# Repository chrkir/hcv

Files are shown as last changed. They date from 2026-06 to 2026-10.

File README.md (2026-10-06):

# Viessmann Vitocal (E3) CAN-Bus to MQTT Bridge with Home Assistant Support

## Please also read the HCV Description in the docu folder.

An isolated, passive CAN-bus adapter to fetch local data from Viessmann E3-generation heat pumps (e.g., Vitocal 250-A, 252-A) and stream it via Wi-Fi to MQTT with native Home Assistant Auto-Discovery.

## 🚀 Key Features

- **100% Local Control:** No internet dependency, no official ViCare Cloud API rate limits.
- **Hardware Protection:** Features full galvanic isolation to protect your expensive heat pump from electrical damage.
- **Passive Sniffing:** Read-only operation ensures zero interference with the heating system's warranty.
- **Plug & Play for Home Assistant:** Built-in MQTT Discovery automatically creates all entities (temperatures, flow rates in L/h, energy in kWh, and states) without writing a single line of YAML.
- **Universal Compatibility:** Works seamlessly with Home Assistant, ioBroker, Node-RED, openHAB, and Symcon.

---

## 🔀 Supported Series & Target Selection (V200 vs. V250)

This project supports both the **E3 Generation (e.g., Vitocal 250-A, 252-A)** and the **V200/WO1C CAN Protocol (e.g., Vitocal 200-S, 200-A, HCV)** via dedicated software builds.

| Feature / Setting | Vitocal 250 (E3 Series) | Vitocal 200 (HCV / WO1C Series) |
| :--- | :--- | :--- |
| **Firmware Target** | Vitocal-250 Build | Vitocal-200 Build |
| **DID Profile File** | `vcalobj.did` | `vcalobj200.did` |
| **DID Format** | Decimal (e.g., `881`, `548`) | Hexadecimal (e.g., `0x0371`, `0x0100`) |
| **Log File** | `canLog250.txt` | `canLog200.txt` |
| **Bus Protocol** | E3 CAN Specification | WO1C CAN Variant |

---

### Selective DID Profile (`vcalobj200.did`) for Vitocal 200

When using the **Vitocal 200 Firmware**, the DID profile file must be uploaded as `vcalobj200.did`. Addresses correspond strictly to the WO1C / HCV hexadecimal address map:

```did
# ==============================================================================
# embdes Viessmann Vitocal 200 / WO1C Custom DID Profile
# Line comments starting with '#' are fully supported.
# ==============================================================================

# Core Temperatures & Controls (WO1C Hex Format)
{0x0100, OutdoorTemp, Aussentemperatur, 0, 1, FLOAT_TEMP_10},
{0x0371, OperatingMode, Betriebsart, 0, 1, INTEGER},
{0x0401, MixerPumpState, StatusMischerPumpe, 0, 1, ON_OFF},

```

## 🛠️ Project Structure & License Model

This project follows a hybrid **Open Hardware / Commercial Software** model to support the community while funding the extensive reverse-engineering work behind the Viessmann CAN protocols.

### 1. Open Hardware (Free)
All hardware files are open-source. You can find the schematics, PCB layout files (KiCAD/EasyEDA), Bill of Materials (BOM), and a 3D-printable enclosure STL file in the `/hardware` folder. Feel free to DIY and order your own boards.

### 2. Pre-Assembled Hardware (Optional)
If you do not want to solder SMD components or lack the equipment, you can buy a fully assembled and tested hardware unit inside its enclosure directly from me for **approx. €35 + MwSt ** (plus shipping from Germany). 

### 3. Firmware & Software License
- **Demo Version (Free):** Includes the local Wi-Fi/MQTT captive portal captive setup, hardware connection test, and displays your unique ESP32 Chip ID.
- **Full Version (€48 + MwSt)** Unlocks all heating data points, daily energy counters, and native Home Assistant Auto-Discovery. It is a one-time payment per device and works **100% offline** (via a license file uploaded to the file system).

---

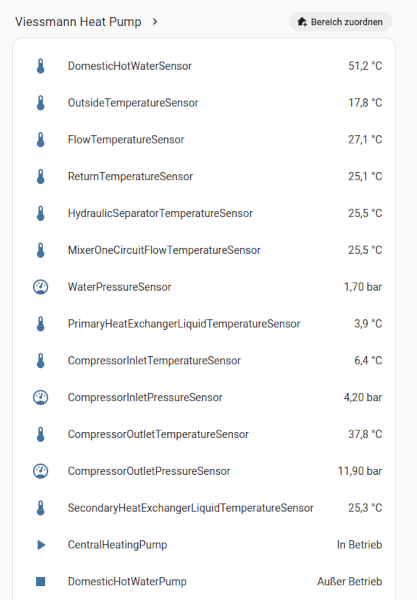
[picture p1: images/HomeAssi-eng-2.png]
Home Assistant Dashboard
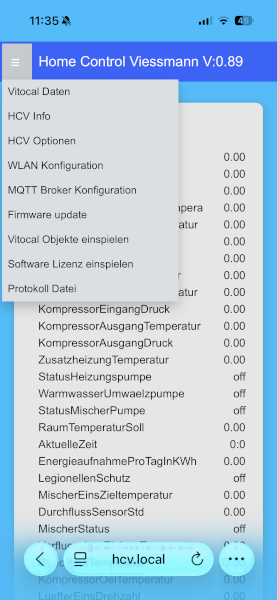
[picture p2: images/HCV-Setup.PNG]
HCV Configuration Options
  

---

## 💻 Getting Started

### Hardware Connection
Connect the adapter to the **INTERNAL** CAN-bus of your Viessmann heat pump (typically labeled as "Plug 72" / Stecker 72 on the main terminal block). 

### Firmware Setup
1. Flash the free firmware build to your ESP32.
2. Power on the device and connect to the Wi-Fi Access Point generated by the adapter.
3. Open `http://192.168.1.1` in your browser, enter your local Wi-Fi and MQTT broker credentials.
4. Copy the unique **Chip ID** shown on the web interface.

### Activating the Full Version
To unlock all sensors and Home Assistant Auto-Discovery:
1. Reach out to me via **PM in the Forums** or via Email at `info@embdes.com` with your **Chip ID**.
2. After payment (€50), you will receive a `license.txt` file.
3. Upload this file through the adapter's web interface and reboot the device.
4. Open Home Assistant ➔ **Settings** ➔ **Devices & Services** ➔ **MQTT**—your heat pump will show up automatically!

---

## 📊 Supported Data Points (Extract)

- **Analogue Sensors:** Flow/Return temperatures, Outdoor temperature, Domestic Hot Water (DHW) temp, Compressor frequency.
- **Flowrates:** Allengra Sensor / Volumetric flow rate (properly formatted in `L/h`).
- **Energy Dashboard:** Daily energy consumption (properly formatted in `kWh` with `total_increasing` state class).
- **Binary States:** Compressor status, Mixer pump status, Error flags (formatted with native `running` and `problem` device classes).

---

## ⚙️ Customizing Data Points (Selective DIDs)

By default, the adapter processes all available data points. To keep your MQTT broker clean and reduce network traffic, you can now upload a custom selection profile via a `vcalobj.did` file through the web interface. 

Only the DIDs specified in this file will be active on the CAN bus, transmitted via MQTT, and displayed in the local web app.

### CAN Bus Logging
* Integrated CAN bus logging to record and analyze raw network traffic.
* Supports capturing all bus messages or filtering by specific CAN IDs to easily discover and map new DIDs for custom MQTT messages.

### Data Identifier (DID) Management & Web Interface
* Structured handling and parsing of Data Identifiers (`vcalobj.did`).
* Responsive Web UI featuring dedicated help text styling to cleanly separate parameter descriptions from real-time sensor data.

### File Format (`vcalobj.did`)

The file must be uploaded as a plain text or CSV-like format using the following structure:
`{ID, Description_Original, Description_Custom, Byte_Position, Display_Flag, DID_TYPE}`

Here is a verified example for a minimal setup (Core temperatures, flowrate, and energy counters).

**Note:** New releases may expand the configuration; the file itself is always the source of truth.

```did
# ==============================================================================
# embdes Viessmann E3 Custom DID Profile
# Remove or add rows to customize your MQTT payload and local dashboard.
# Line comments starting with '#' are fully supported.
# ==============================================================================

# Core Temperatures
{268, FlowTemperatureSensor, Vorlauftemperatur, 0, 1, FLOAT_TEMP_10},
{269, "ReturnTemperatureSensor", "AußeneinheitRücklauftemperatur", ...},
{271, DomesticHotWaterSensor, WarmwasserTemperatur, 0, 1, FLOAT_TEMP_10},
{274, OutdoorTemperatureSensor, Aussentemperatur, 0, 1, FLOAT_TEMP_10},

# Flowrate & Hydraulics
{1043, VolumetricFlowrateSensor, DurchflussSensorStd, 0, 1, FLOAT_LH},

# Energy Dashboard
{548, EnergyConsumptionPerDay, EnergieaufnahmeProTagInKWh, 0, 1, P_KWH},

# Binary States (On/Off)
{401, MixerPumpStatus, StatusMischerPumpe, 0, 1, ON_OFF},
```

### ⚠️ Critical Formatting Rules

To avoid parsing errors on the microcontroller, ensure your `vcalobj.did` strictly adheres to these rules:

1. **No trailing spaces before commas:** Ensure numeric values do not contain spaces before a comma (e.g., use `1,` instead of `1 ,`).
2. **Entity naming:** Avoid special characters like `%` within the custom description strings. Use clean alphanumeric names (e.g., `LuefterEinsDrehzahl` instead of `LuefterEinsDrehzahl%`).
3. **Valid Data Types:** Supported `DID_TYPE` tokens are:
   - `FLOAT_TEMP_10`, `FLOAT_PRES_10`, `FLOAT_PRES_100`
   - `ON_OFF`, `INT_TIME`, `INT_PERC`, `P_KWH`, `P_WATT`
   - `FLOAT_LH`,  `INTEGER`

### How to apply changes

1. Create or edit your `vcalobj.did` file using a standard text editor (like VS Code or Notepad++).
2. Open the adapter's web interface in your browser.
3. Navigate to the **File Upload** section, select your `vcalobj.did` file, and hit upload.
4. The adapter will validate the file, save it to the internal flash storage, and dynamically reload the database into RAM without needing a manual hardware reset.

## 🚗 Integration with evcc (PV Charging Manager)

The embdes adapter can be integrated into [evcc](https://evcc.io) as a passive **heat pump power meter**. Since the adapter operates strictly in **read-only mode**, it is 100% safe and will not interfere with your Viessmann warranty.

To display your heat pump's consumption in evcc, add the following configuration to your `evcc.yaml`:

```yaml
meters:
  - name: viessmann_heatpump
    type: custom
    power:
      source: mqtt
      topic: viessmann/wp/state
      jq: .EnergieaufnahmeProTagInKWh oder EnergyConsumptionCentralHeating # Fetches the daily energy counter from the JSON payload
```

*Note: The adapter acts as a pure data provider (Push-to-MQTT). No active HTTP polling or writing to the CAN-bus is required or supported.*

---

## Web UI Parameter Control (Write Support)

Starting with **v1.14.0**, the HCV Web Interface allows you to adjust parameters directly on the Vitocal 250 heating unit without needing external automation scripts or manual MQTT commands.

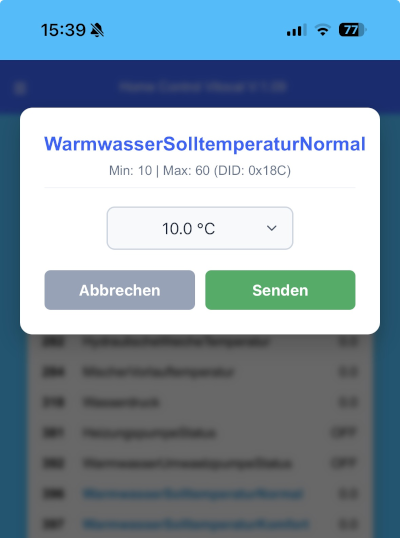
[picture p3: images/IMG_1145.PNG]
HCV Web UI Parameter Control


### Key Features:
* **Direct Web Control:** Click on writable parameters within the dashboard to bring up the interaction dialog.
* **Safety & Boundary Checks:** Displays allowed minimum and maximum boundaries (e.g., `Min: 10 | Max: 60` for `WarmwasserSolltemperaturNormal`) defined by `vcalobj.did` to prevent invalid inputs.
* **DID Transparency:** Clearly displays the active Data Identifier (e.g., `DID: 0x18C`).
* **Instant Bus Dispatch:** Clicking **Senden** formats and transmits the updated setpoint straight to the Vitocal CAN bus.

---

## 🛠️ Changelog & What's New

### Release v1.33
* **Added:**&emsp; Expanded Telnet terminal functions and command handling for remote diagnostics.
* **Added:**&emsp; Dedicated logging for MQTT connection status and WiFi disconnect reason codes.
* **Improved:**&emsp; Enhanced WiFi stability and compatibility with modern routers (PMF handling & disabled modem-sleep).
* **Improved:**&emsp; Reliability of NTP time synchronization across network interfaces.
* **Fixed:**&emsp; Cold-boot panic crash (`ESP_RST_PANIC`) during W5500 Ethernet initialization with plugged cable.
* **Fixed:**&emsp; Byte-alignment offset issue causing incorrect IP address rendering ("IP address all equal").
* **Fixed:**&emsp; Telnet session lifecycle and socket handling for the Ethernet variant.
* **Fixed:**&emsp; Relative boot timestamp calculations and log message update frequency.

### 🆕 New: HCV Ethernet & WLAN Edition - Release 1.30

In addition to the Wi-Fi-only version, the **HCV Ethernet Edition** is now available.

* 🔌 **Dual Connectivity (LAN & Wi-Fi):** Connect either via a standard RJ45 Ethernet network cable or Wi-Fi.
* 📶 **Ideal for Basement Installations:** Maximum stability and reliability – even in utility rooms with poor Wi-Fi reception.
* ⚡ **Same Full Feature Set:** Full support for all CAN data points, Home Assistant Auto-Discovery, and 100% cloud-free local operation.

### Release v1.29
* **Fixed:** Resolved issue with Access Point (AP) mode selection.
* **Fixed:** Fixed main page rendering and display issues in Google Chrome browsers.
* **Fixed:** Corrected DID access for CAN ID `0x693` (Display Unit).
* **Added:** Password visibility toggle in the WebUI configuration panel.

### Hardware 1.6
* **Changed CAN Line protection**

### Release v1.25 – Dynamic VX3 DID Engine & Multi-Mode Support
### 🚀 Key Improvements & Features
* **Dedicated `vx3obj.did` Table File:** Fully decoupled VX3 data points from the standard Vitocal table (`vcalobj.did`).
* **Three Flexible Operating Modes:**
  1. **Heat Pump Only (without VX3):** Standard operating mode for standalone Vitocal heat pump systems.
  2. **Heat Pump + VX3:** Combined mode to read data from both the heating system and the PV/battery storage.
  3. **VX3 Only (without Heat Pump):** Dedicated mode for standalone Vitocharge storage/inverter installations.
* **Enhanced DID Engine (v1.25 / v1.24):** Fully dynamic decoding for all payload sizes (1, 2, and 4 bytes) including Big-Endian processing, signed power values (charge/discharge), and 32-bit multi-frame UDS responses (e.g., grid feed-in/consumption meters like DID 535).

### 📜 Changelog Summary (v1.22 – v1.25)
* **v1.25:** Improved VX3 mode detection and web display logic.
* **v1.24:** Added 32-bit integer handling (P_KWH / P_WATT) and improved sign/endianness processing.
* **v1.23:** Removed page refresh flicker on `httpMain`, corrected write-filter logic (`writeFlg`) for read-only sensor points, and added new VX3 configuration options in the Web UI.
* **v1.22:** Added dedicated VX3 data handler (active & passive mode), introduced `vx3obj.did` file, and fixed `vcalobj.did` mappings (corrected DID 534/535 to 526/528).

### Enhancements (v1.21)
* **Multi-Frame DID Support:** Added ISO-TP multi-frame decoding support for long DIDs spanning multiple CAN messages. 

### Bug Fixes & Stability (v1.20)
* **Critical Wi-Fi Auto-Connect Fix:** Corrected WiFi.begin() parameter passing in auto-select mode, resolving connection issues when BSSID lock is unused.
* **Wi-Fi 6 (802.11ax) Support:** Explicitly enabled 802.11ax protocol support on ESP32-C6 targets (TARG_V250_C6) to prevent connection timeouts on Wi-Fi 6 routers (e.g., FRITZ!Box AX).
* **AP Mode Wi-Fi Scanning:** Configured AP mode to run in dual WIFI_AP_STA mode to allow asynchronous scanning of nearby networks during setup.
* **Watchdog Stability (TWDT Fix):** Offloaded OTA reboot and factory reset operations from the async_tcp task context to prevent Task Watchdog resets.

### New Features & UI Enhancements
* **SSID Selection Dropdown:** Populates nearby Wi-Fi SSIDs with signal strength indicators (dBm) directly from the scan cache.
* **Web UI Factory Reset:** Added factory reset trigger into the setup dropdown menu (accessible exclusively in AP mode with safety prompt).
* **Clean UI Formatting:** Improved active SSID dropdown rendering.

### 🐛 Bug Fixes & Refinement (v1.19)
* **CAN Data Display:** Fixed an issue introduced in v1.18 where CAN data was not displaying correctly in the interface.
* **DID Integer Display:** Fixed false DID value formatting and display for integer units.

### 🌐 MQTT & System Stability (v1.18)
* **Home Assistant Auto-Discovery:** Fixed HA Discovery functionality upon MQTT reconnect, including proper handling of retained messages.
* **Boot State Display:** Set default DID value display to `--` right after HCV boot until valid data is received.
* **DID Object Management:** Fixed automatic reloading of DID objects immediately after a new file upload.
* **Wi-Fi Auto-Reconnect:** Improved Wi-Fi reconnect mechanism by resetting the Wi-Fi channel after a timeout event.

### ⚙️ System Control & Network Configuration (v1.16 – v1.17)
* **Global Reset:** Added a global system reset function with safe CAN bus deinitialization (`can deinit`).
* **Wi-Fi Manager:** Reworked Wi-Fi configuration with integrated Access Point (AP) selection.

---

## ⚠️ Upgrade Note
If you are upgrading from v1.18, updating to **v1.19.0** is strongly recommended to resolve the CAN data display issue.

## ✉️ Contact & Support

If you want to buy a pre-assembled board or a software license, please contact me:
- **Home Assistant Forum:** [@chrkir](https://home-assistant.io)
- **ioBroker Forum:** [@chrkir](https://iobroker.net)
- **Email:** `info@embdes.com`

*Disclaimer: This is a third-party community project. This project is not affiliated with, authorized, or endorsed by Viessmann.*

## Links & Resources

- [GitHub Repository](https://github.com/chrkir/hcv)
- [Dokumentation](https://github.com/chrkir/hcv/tree/main/docu)
- [Hardware Ordner](https://github.com/chrkir/hcv/tree/main/hardware)
- [Software Ordner](https://github.com/chrkir/hcv/tree/main/software)

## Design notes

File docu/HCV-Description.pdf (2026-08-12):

# HCV Module for Viessmann Vitocal Heat Pumps

## Description

HCV (Home Control Viessmann) is an adapter that integrates Viessmann heat pumps supporting E3 communication via CAN into a home control environment, without requiring advanced technical knowledge. In other words, apart from connecting the HCV module to the internal CAN bus and configuring Wi-Fi access, no further settings or expertise are required.

Once installed, data retrieved via the CAN bus can be viewed using any local web browser.
If integration into a home control environment is not required, the installation process is complete at this stage. Current data can then be queried at any time by navigating to the address hcv.local in a browser.

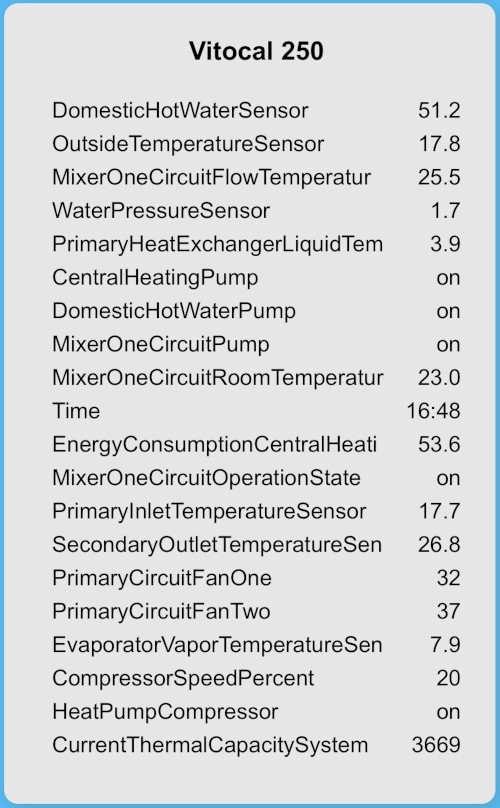
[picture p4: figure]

## Initial Installation and Reset

By default, the integrated Access Point mode is active, allowing the HCV module to be accessed via the address `192.168.1.1`. This state is indicated by a flashing red LED. The network named "HCV" will appear in your mobile phone's network settings and can be selected. Once connected, you can enter and save your local network's credentials (SSID and password). To switch to standard Wi-Fi mode: disconnect the power supply

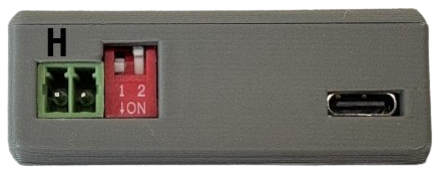
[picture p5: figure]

(USB plug), flip switch 2 to the "OFF" position, and reconnect the power. Once the HCV module's status LED flashes green, the device can be accessed via the regular Wi-Fi network using the address `hcv.local`.

Note: Under the "Vitocal Data" menu item—which also serves as the HCV module's main page—the message "No device detected" is displayed if no valid CAN messages are detected. The display updates once at least one valid message is recognized.
The messages in the "Vitocal 250" window are displayed in either German or the origin defined E3onCan messages.

In the event of an issue, the local network settings can be modified at any time by flipping switch 2 to the "ON" position and subsequently restarting the device.

## MQTT Broker Configuration

Once a connection has been successfully established, the broker's address—and, if applicable, the username and password—can be entered via the "MQTT Broker Config" menu option. Saving the configuration data triggers a restart of the HCV module.
As soon as CAN messages valid for a Vitocal heat pump are detected, they also appear as MQTT messages on the local network or within the MQTT broker.

Note: The values (DIDs) currently defined in the Open3E datapoints are the ones transmitted.

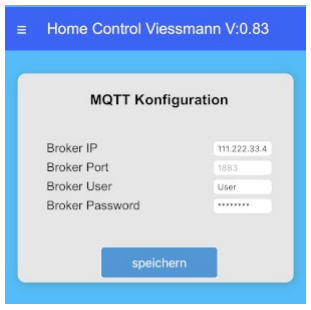
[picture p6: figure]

We would like to take this opportunity to thank the creators of the document that served as the basis for the CAN messages for their work.

As previously mentioned, the CAN messages displayed in the browser are translated into German. The same setting can be applied to MQTT messages by selecting "German" under the "HCV Options" menu item. The advantage of the German version is that the MQTT messages are shorter.

## MQTT Broker Message Format

The MQTT messages displayed and sent by the HCV module can be customized. Either the data IDs defined in the OpenE3datapoints document are used, or the German-language text strings are employed. This selection can be found under the "HCV Options" menu item.

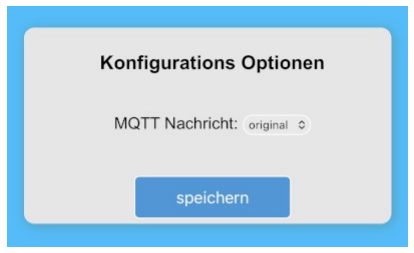
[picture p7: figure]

## CAN Bus Installation

The connection for detecting messages from Viessmann heat pumps is made via the internal CAN bus connector 72 of the Vitocal indoor unit. Since this connection is already in use, the
HCV module's sensor cable must be connected in parallel. Pay attention to the CAN bus polarity when doing so. The terminal on the HCV module corresponding to CAN High is marked in black.
Setting switch 1 to the "ON" position activates the CAN terminating resistor. This must be switched off when using the internal connection!

Note: The maximum length of the cable between the Vitocal connection and the HCV module connector must not exceed 10 meters.
It should also be noted that the CAN connection is galvanically isolated to

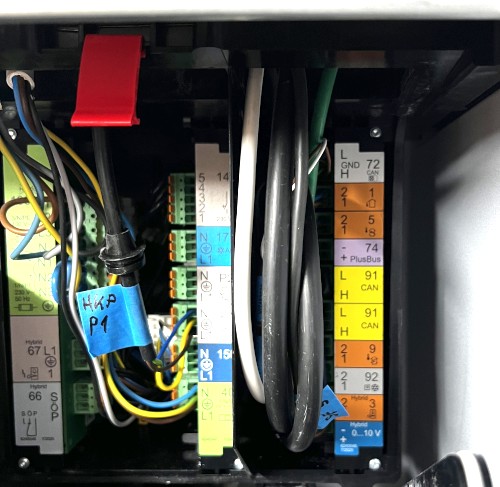
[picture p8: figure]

prevent interference on both the CAN bus and the connected devices.

## Status LED

LED flashes red: Access Point mode is selected via switch 2, or there is no connection to the configured local Wi-Fi.
LED flashes red and green: Connection to the local Wi-Fi is established, but there is no MQTT connection to a broker.
LED flashes green: Wi-Fi and MQTT connections are active.

## HCV Firmware Update

The HCV module's software can be updated via OTA (Over-the-Air), meaning directly over the network. Current versions are available on the embdes.com website and under github /chrkir/hcv. In the HCV menu, you will find this function under "Firmware update".

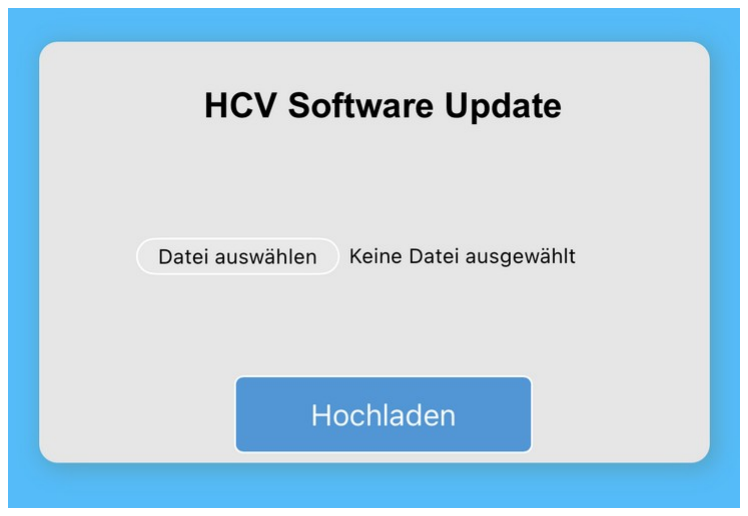
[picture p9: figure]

## Support

For questions, errors, or suggestions, please write to info@embdes.com.

## Configuration Settings

The main page displays configuration data read from the `vcalobj.did` file. The corresponding values are updated based on received CAN messages and simultaneously transmitted via the MQTT connection. This page can be accessed via the "Vitocal Data" menu option.

The "HCV Info" menu option displays function-relevant data as well as the internal memory allocation.

The "Settings" option is used to configure CAN communication settings. The control software you are using is a key factor here. A JSON format has been implemented specifically for home automation software, allowing for the automatic registration of data to be transmitted. All other systems operate using the "MQTT Individual Messages" selection or, in some cases, the JSON format. For all variants, it is important not to change the selected MQTT format after initial testing; otherwise, the application software may fail to process the messages.

Wi-Fi configuration allows you to set the SSID and password.

The MQTT Broker configuration section is used to set the

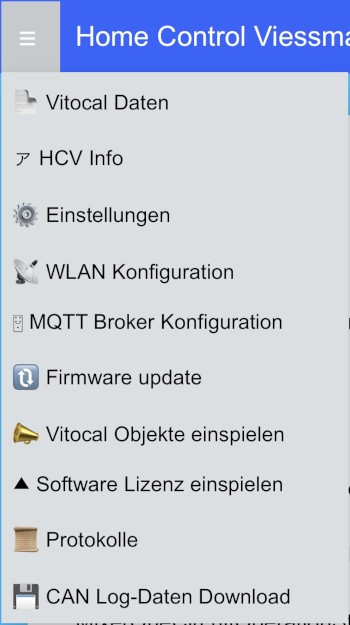
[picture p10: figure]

broker IP, port, username, and password.

"Firmware Update" allows you to install a new software version; these versions can be downloaded from embdes.com or github/chrkir/hcv.

"Import Vitocal Objects" loads either the basic configuration provided by embdes or an extended/modified variant into the HCV adapter. The settings for the data to be imported are described in the `vcalobj.did` file. If in doubt, please contact embdes for support.

The "Import Software License" function allows you to activate self-built hardware for use as licensed hardware. Hardware supplied by embdes is already activated.

Messages regarding events relevant to the adapter's operation are written to the log file. These messages can be viewed, transmitted, and deleted using the corresponding function. CAN Log Data Download: If CAN logging is enabled in the settings, this option allows you to download the stored CAN log data to your PC. Before the transfer, the data is converted into a Linux-compatible candump format. This data can be used to extend or customize the Viessmann Data IDs (DIDs) for analysis purposes. Relevant information can be found at: github/../e3oncan.

HCV MQTT ioBroker - Home Control – Node red ….

If the MQTT messages are to be integrated into a home automation application, this can be done by simply selecting the corresponding objects in the ioBroker MQTT tree. Other home control applications also accept this format; in some cases, the MQTT variant in JSON format is supported as well, offering the advantage of reduced system load.

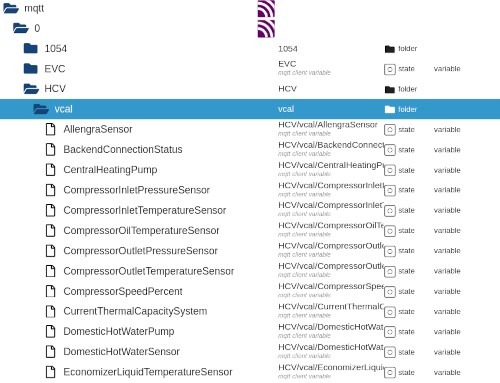
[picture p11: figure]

## HCV MQTT Home Assistant

As previously mentioned in the "Message Format" section, the HCV supports Home Assistant via a custom MQTT implementation. If the MQTT service is installed and enabled in Home Assistant, the Viessmann Vitocal heat pump is automatically detected and installed. Once the HCV module is connected to the internal CAN bus, automatic registration is initiated upon powering up the module. The values received from the control unit are then displayed in the Home Assistant "Devices" overview and continuously updated.

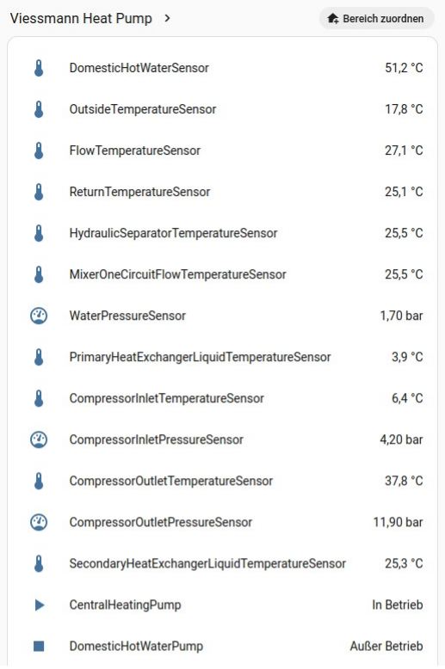
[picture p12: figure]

## Firmware Changes:

Version: 0.89
Support for Home Assistant.

Version: 0.90
Configuration file upload for Data IDs (DIDs) via the Settings menu; MQTT password length increased to 32 characters. Protocol control via a dedicated display.

Version: 0.91
CAN logging added. Messages not already loaded via the `vcalobj.did` configuration settings are recorded in Linux `candump` format.

Version: 1.01
Active control of the Vitocal (write operations for DIDs):
Functionality has been expanded to include writing Data IDs (DIDs). Specific Vitocal parameters can now be adjusted via an MQTT message in JSON format.
- Transmit topic: `HCV/writeDid`
- Example payload (set room temperature setpoint for mixer circuit 1 to 20 °C): `{"did": 424, "value": 200}`
(Note: The value 200 corresponds to 20.0 °C, as this data point is defined as `Float_10` in `vcalobj.did` and is scaled by a factor of 10.)
- Feedback / Status:
The response from the Vitocal controller is reported back transparently via MQTT:
- Topic: `HCV/writeDidResponse`
- Payload: `{"status": "success"}` or `{"status": "error"}`
- Filter function for CAN logging:
CAN logging now offers a flexible filter function. Users can choose whether to record all messages on the CAN bus or only specific CAN IDs. This significantly simplifies analysis when extending pre-configured MQTT messages or identifying new data points.
- Recorded data can be downloaded to the PC's local download folder via the "CAN Log Data Download" menu item. Since this data is available in a binary format, it can be converted into a readable text format using the integrated CAN Log Converter tool. This format can also be played back for simulation purposes using the Linux program `canplayer`.
- Enhanced DID handling & configuration updates:
The new data structure handling allows for more flexible management and updating of DIDs, enabling the integration of new control and read options into the system with minimal effort.
- Optimized user interface:
Improved display of help text and parameter descriptions in the web interface, ensuring a clearer distinction between setting explanations and live measurement values.
Data objects that can be modified are highlighted in color (blue).

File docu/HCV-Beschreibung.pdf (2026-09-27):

# HCV Modul für Viessmann Vitocal Wärme Pumpen

## Beschreibung

HCV - Home Control Viessmann ist ein Adapter der Viessmann Vitocal Wärmepumpen, die die E3 Kommunikation über CAN unterstützen, in eine Home Control Umgebung ohne erweiterte technische Kenntnisse integriert. D.h. außer dem Anschluss des HCV-Modul an den internen CAN-Bus an die Klemme 72 und die Konfiguration des WLAN Zugangs sind keine weiteren Einstellungen / Kenntnisse erforderlich.

Nach der Installation können über jeden lokalen Browser die über den CAN-Bus ausgelesenen Daten angezeigt werden.

Ist keine Einbindung in eine Home Control Umgebung erforderlich ist die Installation damit abgeschlossen. Nun kann zu jedem Zeitpunkt eine Abfrage der aktuellen Daten über die Browser Adresse hcv.local erfolgen.

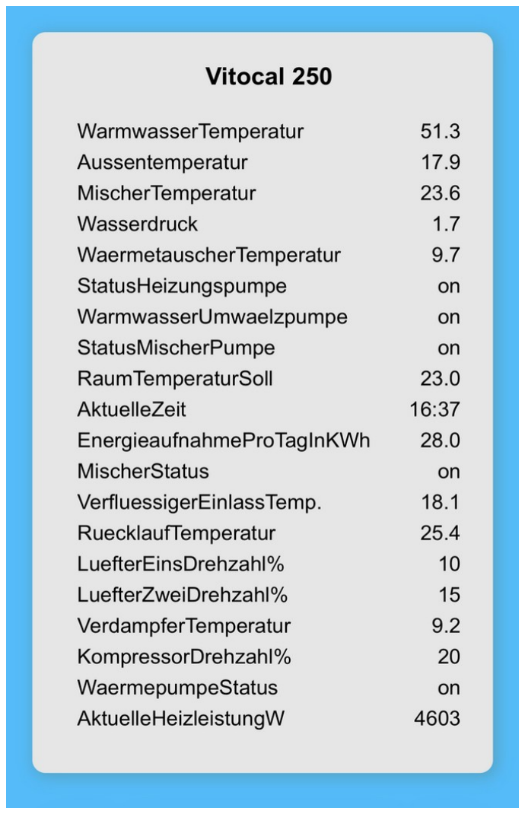
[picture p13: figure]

## Netzwerkanbindung & Erstinbetriebnahme

Gerätevariante: Ethernet

Bei Geräten mit verbautem W5500 Ethernet-Modul hat die LAN-Verbindung oberste Priorität. Es ist keine Erstkonfiguration über WLAN erforderlich bzw. Auch nicht möglich.

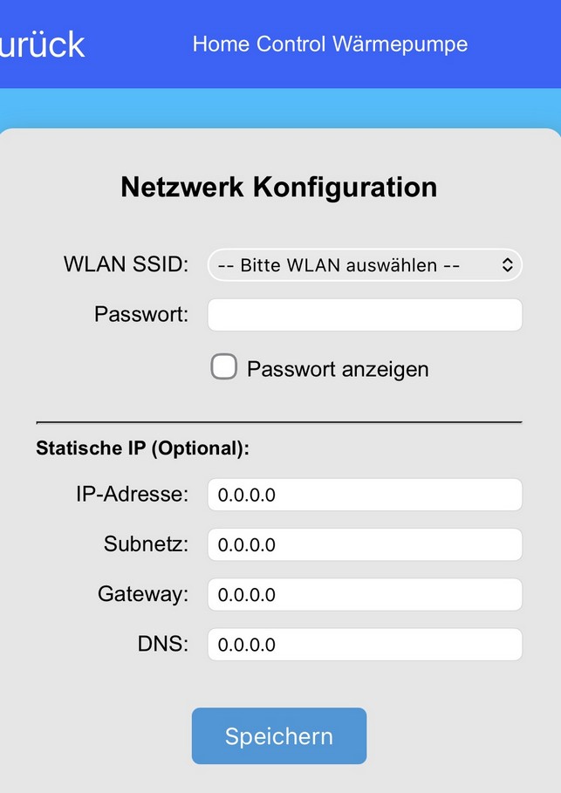
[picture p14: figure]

Inbetriebnahme:
- Netzwerkanbindendes LAN-Kabel an die RJ45-Buchse des HCV-Moduls anschließen.
- Versorgungsspannung (USB-Stecker) anstecken.
- Das Modul bezieht automatisch per DHCP eine IP-Adresse von Ihrem Router.
- Sobald die Status-LED rot/grün blinkt, ist das Modul
betriebsbereit und im | lokalen | Netzwerk | über
http://hcv.local (https://www.google.com/search?q=http%3A%2F%2Fhcv.local) erreichbar.

Gerätevariante: WLAN (Wi-Fi)

Geräte ohne Ethernet-Schnittstelle starten bei der Erstinbetriebnahme oder ohne gespeicherte WLAN-Daten automatisch im Access-Point-Modus (AP-Modus).

Inbetriebnahme:
- Versorgungsspannung (USB-Stecker) anstecken.
- Die Status-LED blinkt rot (AP-Modus aktiv).
- Am Smartphone oder PC mit dem WLAN „HCV-AP“ (ohne Passwort) verbinden.
- Im Browser die Adresse http://192.168.3.1 (http://192.168.3.1/?utm_source=gemini) aufrufen.
- In den Netzwerkeinstellungen das eigene WLAN-Netzwerk (SSID) auswählen, das Passwort eingeben und auf Speichern klicken.
- Das HCV-Modul startet automatisch neu, verbindet sich mit Ihrem WLAN und ist nach dem Neustart (Status-LED blinkt rot/grün) unter http://hcv.local (https://www.google.com/search?q=http%3A%2F%2Fhcv.local) erreichbar.

AP-Modus manuell starten (Notfall- & Service-Zugang)
Sollte das WLAN-Passwort geändert worden sein, ein Wechsel des Routers anstehen oder bei Ethernet-Geräten ein Notfall-Zugriff benötigt werden, kann der AP-Modus jederzeit manuell erzwungen werden:
A) Hardware-Version ab v1.5 (ohne roten Schalter)
- Versorgungsspannung (USB) abziehen.
- Den rückseitigen Taster hinter der kleinen Gehäuseöffnung gedrückt halten.
- Versorgungsspannung anstecken und Taster nach 2 Sekunden loslassen.
- Die Status-LED blinkt rot der AP-Modus ist aktiv unter http://192.168.3.1.
B) Vorläufer-Hardware (mit DIP-Schaltern)
- Schalter 2 am DIP-Schalterblock in Stellung ON bringen.
- Versorgungsspannung anstecken.
- Sobald die Status-LED rot blinkt (AP-Modus aktiv), Schalter 2 wieder auf OFF zurückstellen.
- Das Modul ist nun unter http://192.168.3.1 (http://192.168.3.1/?utm_source=gemini) erreichbar.

Störungsfall & Firmware-Update

Firmware-Update im Notfall: Sollte das HCV-Modul im normalen Netzwerk nicht mehr erreichbar sein oder ein Update fehlschlagen, starten Sie den AP-Modus wie oben beschrieben und rufen Sie direkt die Update-Seite http://192.168.3.1/fwupdate (http://192.168.3.1/fwupdate?utm_source=gemini) auf.

Werkszustand (Factory Reset): Über den Menüpunkt im Web-Interface oder per Telnet-Verbindung (telnet 192.168.3.1) können alle gespeicherten Einstellungen gelöscht werden, um das Modul komplett zurückzusetzen, d.h. in den Auslieferungszustand.

Statische IP-Adresse (Optional)

Standardmäßig bezieht das HCV-Modul seine Netzwerkeinstellungen sowohl im Ethernet- als auch im WLAN-Betrieb automatisch per DHCP vom Router.
- Manuelle IP-Vergabe: Falls eine feste IP-Adresse im Netzwerk benötigt wird, kann diese in den Netzwerkeinstellungen (im regulären Betrieb unter http://hcv.local (https://www.google.com/search?q=http%3A%2F%2Fhcv.local) oder im AP-Modus unter http://192.168.3.1) (http://192.168.3.1/?utm_source=gemini) für IP-Adresse, Subnetzmaske, Gateway und DNS eingetragen werden.
- Rückkehr zu DHCP: Um eine statische Konfiguration aufzuheben und wieder die automatische IP-Vergabe (DHCP) zu aktivieren, tragen Sie in den Feldern für die IP-Adresse einfach 0.0.0.0 ein und speichern die Einstellungen.

## MQTT Broker Konfiguration

Über die Menü-Auswahl MQTT Broker Konfig kann nach erfolgreicher Verbindung die Adresse und ggf. Benutzer und Passwort des Brokers eingegeben werden, wobei der Benutzername max. 15 Zeichen und das Passwort max. 32 Zeichen betragen kann. Mit dem Speichern der Konfigurationsdaten erfolgt ein Neustart des HCV-Modul.
Sobald CAN-Nachrichten, die für eine Vitocal Wärmepumpe gültig sind, erkannt werden, erscheinen diese auch auch als MQTT-Nachricht im lokalen Netzwerk bzw. im MQTT-Broker.

Hinweis: Es werden immer die in dem OpenE3-

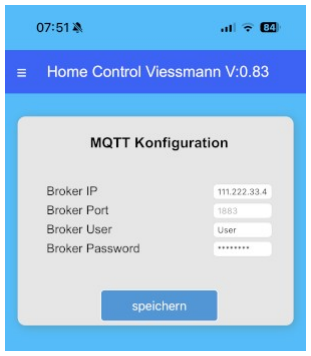
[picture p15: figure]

datapoins als aktuell definierten Werte (DID) übertragen.

An diesem Punkt möchten wir uns bei den Erstellern dieses Dokuments, das als Ausgangsbasis für die CAN-Nachrichten gedient hat, für ihre Arbeit bedanken.

Wie bereits erwähnt, sind die im Browser angezeigten CAN-Nachrichten ins deutsche übersetzt. Gleiches kann man dies auch für die MQTT Nachrichten einstellen, wenn man unter dem Menü Punkt HCV Optionen die Einstellung „deutsch“ wählt. Der Vorteil der deutschen Version sind kürzere MQTT Nachrichten.

## MQTT Broker Nachrichten Format

Die von dem HCV-Modul angezeigten und verschickten MQTT Nachrichten können angepasst werden. Entweder werden die in dem OpenE3datapoins Dokument definierten Daten ID’s verwendet oder es werden die eingedeutschten Texte benutzt. Die Auswahl ist unter dem Menüpunkt HCV Optionen zu finden. Wird eine bestehende Konfiguration nachträglich geändert, muss das Modul neu gestartet werden. Eine weiter Option ist, das Format der MQTT-Nachrichten an die Home Control Umgebung anzupassen. Für die Varianten von z.B. ioBroker, Node red, Home Control etc. sollte die MQTT Einzelnachricht gewählt werden. Für Home Assistant wurde das spezielle Discovery implementiert

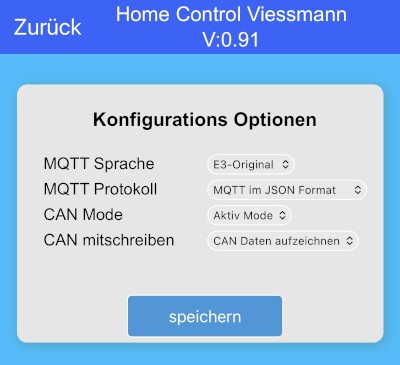
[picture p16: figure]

und es muss MQTT im JSON Format gewählt werden.

## CAN-Bus Installation

Der Anschluss für die Nachrichtenerkennung der Viessmann Wärmelumpen erfolgt über den internen CAN-Bus auf dem Anschluss 72 der Vitocal Inneneinheit. Da dieser Anschluss bereits belegt ist, muss die Sensor Leitung des HCV-Moduls parallel angeschlossen werden. Dabei ist auf die Polung des CAN-Bus zu achten. Der Anschluss des CAN-Steckers an dem HCV-Modul der dem CAN High entspricht, ist schwarz markiert, bzw. mit „H“ markiert. Mit der ON-Stellung des Schalters eins wird der CAN Abschlusswiederstand eingeschaltet. Dieser muss im Fall des internen Anschluss ausgeschaltet sein! Im Fall das CAN-Daten an dem externen Anschluss 91 aufgezeichnet werden sollen, muss dieser Switch wahrscheinlich auf ON gestellt werden. Dies muss aber durch eine Messung überprüft werden.
Der | Widerstand | eines | korrekt
abgeschlossenen CAN beträgt 60-Ohm.


Hinweis: Die Messung muss mit ausgeschalteter Einheit erfolgen.
Die maximale Länge zwischen dem Vitocal Anschluss und dem Stecker des HCV-Moduls darf 10m nicht übersteigen.

Außerdem ist anzumerken, dass der CAN Anschluss des HCV-Adapter galvanisch getrennt ist, um Störungen sowohl auf dem CAN-Bus als auch den angeschlossenen Geräten auszuschließen.

## Status LED

LED blinkt rot: Mit dem Schalter 2 ist der Access-Point Mode ausgewählt oder es besteht keine Verbindung zu dem Konfigurierten lokalen WLAN.
LED blinkt rot+grün: Verbindung zum lokalen WLAN hergestellt, aber keine MQTT Verbindung mit einem Broker vorhanden.
LED blinkt grün: WLAN und MQTT Verbindung sind aktiv.

## HCV Firmware update

Die Software des HCV-Moduls kann per OTA (Over-the-Air-Update), das heißt direkt über das Netzwerk, eingespielt werden. Aktuelle Versionen werden über die Homepage von embdes.com und github/chrkir/hcv angeboten. Im HCV-Menü finden Sie die Funktion unter „Firmware update“.

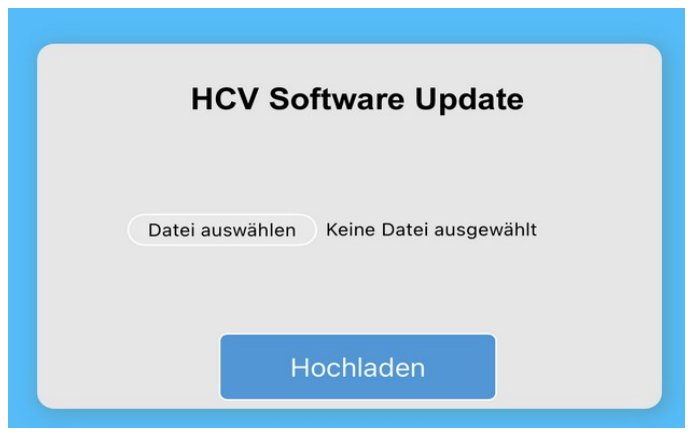
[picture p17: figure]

## Konfigurationseinstellungen

Auf der Hauptseite werden die Konfigurationsdaten angezeigt, die aus der Datei der vcalobj.did eingelesen wurden. Die zugehörigen Werte werden von den empfangenen CAN-Nachrichten aktualisiert und zeitgleich über die MQTT-Verbindung übertragen. Diese Seite kann über die Menüauswahl Vitocal Daten aufgerufen werden.

Über die Menüauswahl HCV Info werden funktionsrelevante Daten sowie die Belegung des internen Speichers angezeigt.

Mit der Option Einstellungen wird die Konfiguration der CAN Kommunikations-Einstellungen vorgenommen. Wichtig dabei ist, welche Kontrollsoftware sie einsetzen. Speziell für die Software von Home-Automation wurde das Json-Format implementiert, das ein automatische Registrierung der zu übertragenden Daten erlaubt. Alle anderen Systeme laufen mit der Auswahl MQTT-Einzelnachrichten bzw. zum Teil auch mit dem Json-Format. Wichtig bei allen Varianten ist, das die Auswahl der MQTT-Sprache nach einem Test nicht mehr verändert wird, da ansonsten bei der Verarbeitung durch die Applikationssoftware Nachrichten nicht mehr verarbeitet werden können.


Die WLAN Konfiguration erlaubt die Konfiguration von SSID und Passwort.

In der MQTT Broker Konfiguration werden Broker IP, Port, Benutzer und Passwort konfiguriert.

Firmware update erlaubt das Einspielen einer neuen Softwareversion, die über embdes.com und github/chrkir/hcv heruntergeladen werden können.

Mit Vitocal Objekte einspielen wird die entweder von embdes zur Verfügung gestellte Grundkonfiguration oder einer erweiterten / geänderten Variante in den HCV-Adapter übernommen. Die Einstellungen der Daten, die übernommen werden sollen sind in der vcalobj.did beschrieben. Im Zweifel sollten Sie auf die Unterstützung von embdes zurückgreifen.

Über die Funktion Software Lizenz einspielen kann eine selbsterstellte Hardware für eine Nutzung der Lizenzierten Hardware freigeschaltet werden. Für alle von embdes gelieferten Hardware ist die Freigabe bereits erfolgt.

Für Ereignisse die für die Funktion des Adapters relevant sind, werden Nachrichten in die Protokoll Datei geschrieben. Diese Nachrichten werden über die Funktion angezeigt, können übertragen und gelöscht werden.

CAN Log-Daten Download: Wen in den Einstellungen das CAN-Logging erlaubt ist, können mit dieser Auswahl die gespeicherten CAN-Loggdaten per Download auf Ihren PC übertragen werden. Die Daten werden vor der Übertragung in ein Linux kompatibles candump Format konvertiert. Mittels dieser Daten kann eine Erweiterung/Anpassung der Daten ID’s (DID) von Viessmann für die Auswertung erfolgen. Entsprechende Informationen finden sie unter: github/../e3oncan.

## Support

Bei Fragen, Fehlern, Anregungen schreiben Sie bitte an info@embdes.com.

## HCV MQTT ioBroker – Home Control - Node red

Sollen die MQTT Meldungen in eine Home Anwendung eingebunden werden, kann dieses durch einfache Auswahl der entsprechenden Objekte im MQTT-Baum des ioBroker erfolgen.
Weiter Home Control Anwendungen akzeptieren dieses Format gleichfalls, wobei auch teilweise die MQTT Variante im JSON-Format akzeptiert wird, was den Vorteil der geringeren Systembelastung mit sich bringt.

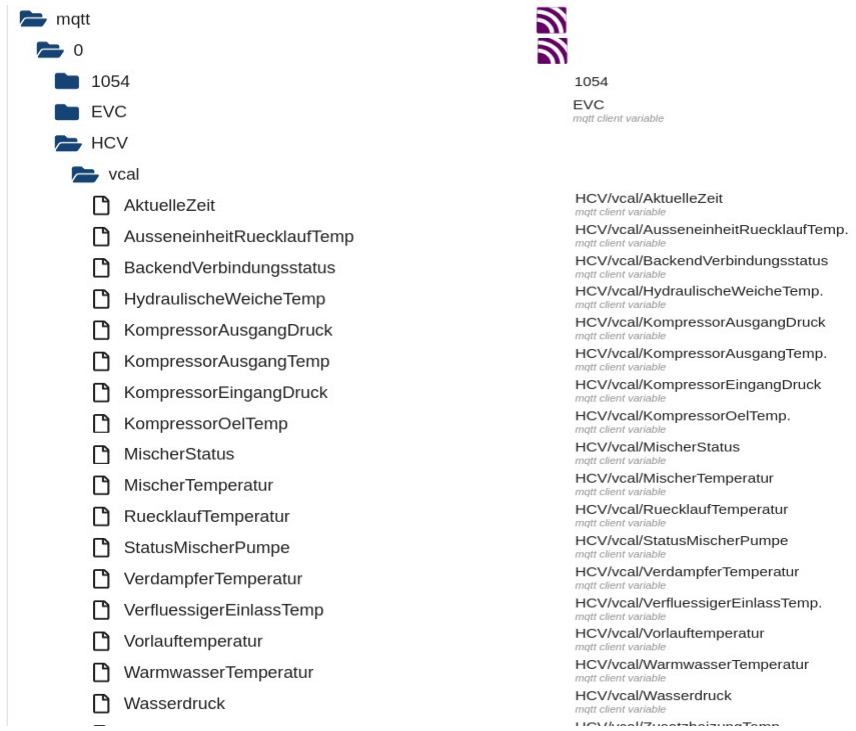
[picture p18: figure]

## HCV MQTT Home Assistant

Wie bereits unter dem Punkt Nachrichten Format erwähnt, unterstützt HCV den Home Assistant mit einer angepassten MQTT Implementierung. Ist im HA der Dienst MQTT installiert bzw. freigegeben, erfolgt eine Erkennung und Installation für die Viessmann Vitocal Wärmepumpe Automatisch. Nach Anbindung des HCV-Modules an den Internen CAN-Bus wird mit dem Einschalten
des | HCV-Modules | eine | automatische
Registrierung | angestoßen. | In | der
Übersicht→Geräte des Home Assistant werden dann die passiv aufgenommen Werte der Steuereinheit angezeigt und fortlaufend angepasst.

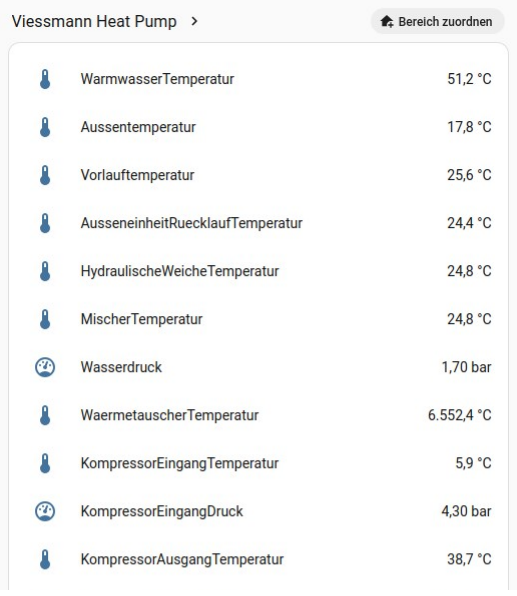
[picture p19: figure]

## Firmware Änderungen:

Version: 0.89 - Unterstützung für Home Assistant.

Version: 0.90 - Konfigurationsdatei für Data ID’s (DID) per Upload über das Menü Einstellungen, MQTT Passwort Länge auf 32 Stellen geändert. Steuerung der Protokolle über eigene Anzeige.

Version: 0.91 - CAN – Logging hinzugefügt. Es werden die Nachrichten, die nicht bereits über die Konfigurationseinstellungen der Datei vcalobj.did geladen sind, im Linuxcandump Format aufgezeichnet.

Version: 1.01
Aktive Steuerung der Vitocal (Schreiboperationen für DIDs):
Die Funktionalität wurde um das Schreiben von Data-IDs (DIDs) erweitert. Über eine MQTT-Nachricht im JSON-Format können nun gezielt Parameter der Vitocal angepasst werden.
- Sende-Topic: HCV/writeDid
- Beispiel-Payload (Raumtemperatur-Sollwert Mischerkreis 1 auf 20 °C setzen): {"did": 424, "value": 200}
(Hinweis: Der Wert 200 entspricht 20,0 °C, da dieser Datenpunkt in der vcalobj.did als Float_10 definiert ist und mit Faktor 10 skaliert wird.)
- Rückmeldung / Status:

Die Antwort der Vitocal-Steuerung wird transparent per MQTT zurückgemeldet:
- Topic: HCV/writeDidResponse
- Payload: {"status": "success"} bzw. {"status": "error"}
- Filterfunktion für das CAN-Logging:
Das CAN-Logging bietet nun eine flexible Filterfunktion. Anwender können wählen, ob alle Nachrichten auf dem CAN-Bus aufgezeichnet werden sollen oder nur spezifische CAN-IDs. Dies erleichtert die Analyse spürbar, wenn vorkonfigurierte MQTT-Nachrichten eigenständig erweitert oder neue Datenpunkte identifiziert werden sollen.
- Die aufgezeichneten Daten können unter dem Menüpunkt CAN Log-Daten Download in den lokalen Download Ordner des PC heruntergeladen werten.
Da diese Daten in einem Binären Format vorliegen könne sie mit dem integrierten Konvertierungsprogramm CAN Log-Converter in ein lesbares Textformat konvertiert werden. Dieses Format kann auch mit dem Linux Programm canplayer zu Simulationszwecken wieder abgespielt werden.

- Erweitertes DID-Handling & Konfigurations-Updates:
Durch das neue Datenstruktur-Handling lassen sich DIDs flexibler verwalten und aktualisieren, um neue Steuerungs- und Lese-Optionen ohne großen Aufwand im System zu verankern.
- Optimierte Benutzeroberfläche:
Verbesserte Darstellung der Hilfetexte und Parameterbeschreibungen im Web-Interface für eine klarere Trennung zwischen Einstellungs-Erklärungen und Live-Messwerten.
Datenobjekte die geändert werden können werden farblich (blau) hervorgehoben.

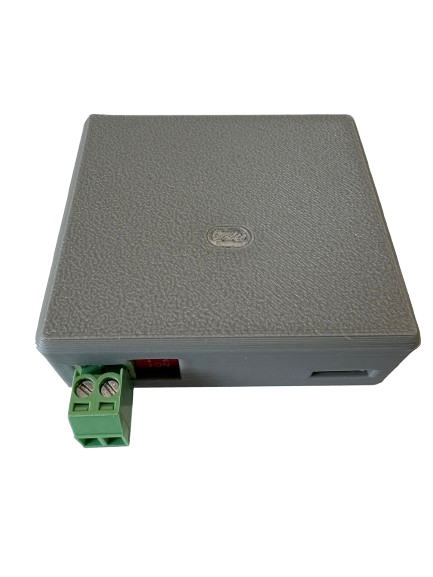
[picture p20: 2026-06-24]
images/HCV-Module.png

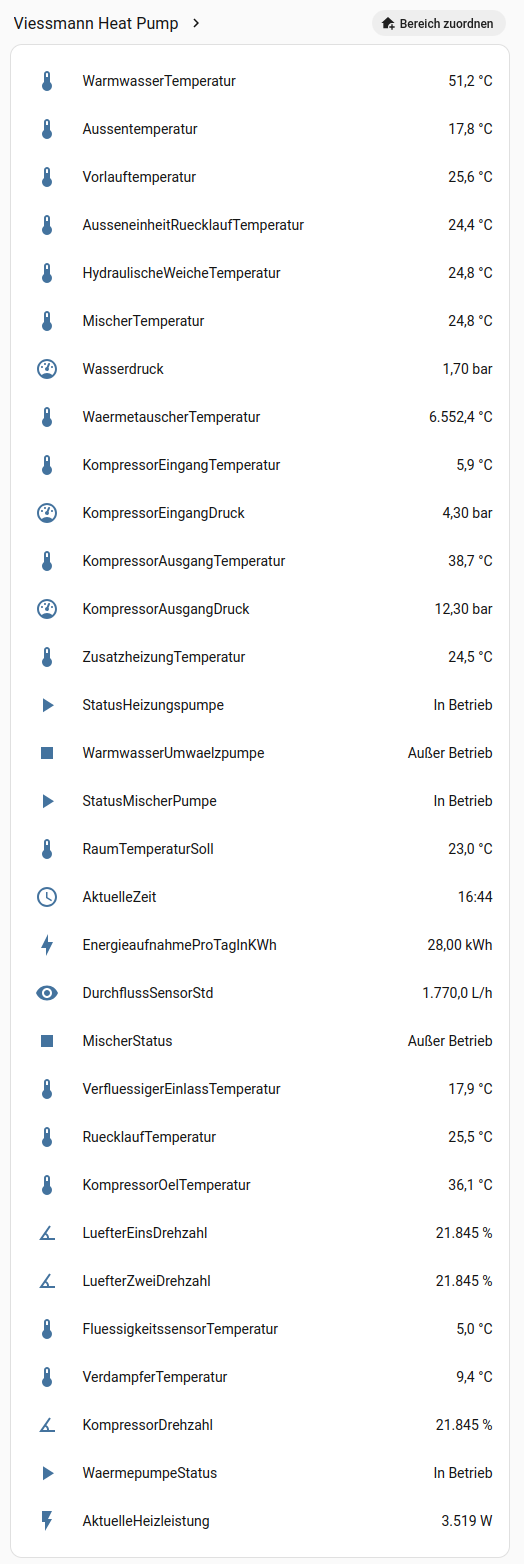
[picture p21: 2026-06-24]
images/HomeAssi-deu.png

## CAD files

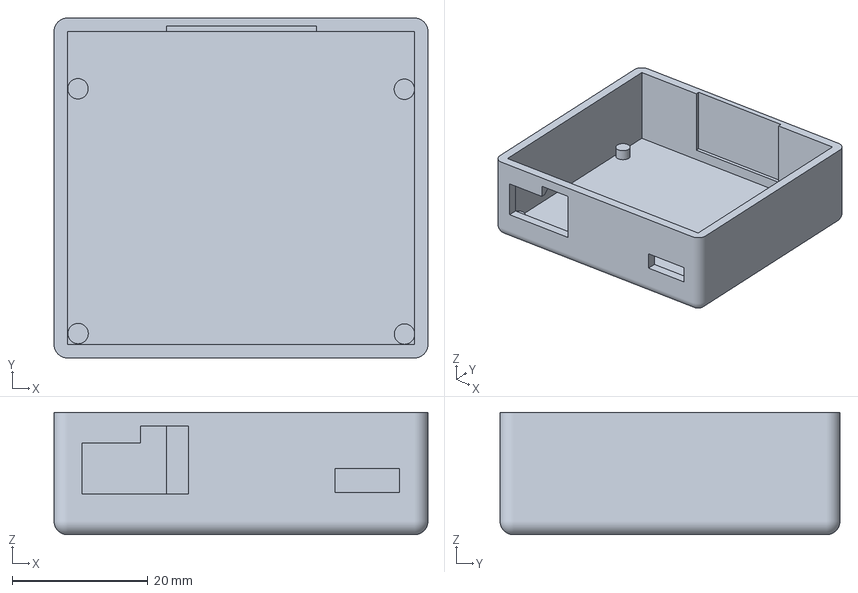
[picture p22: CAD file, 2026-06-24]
hardware/HCV-Körper.3mf
55.0 x 50.0 x 18.0 mm

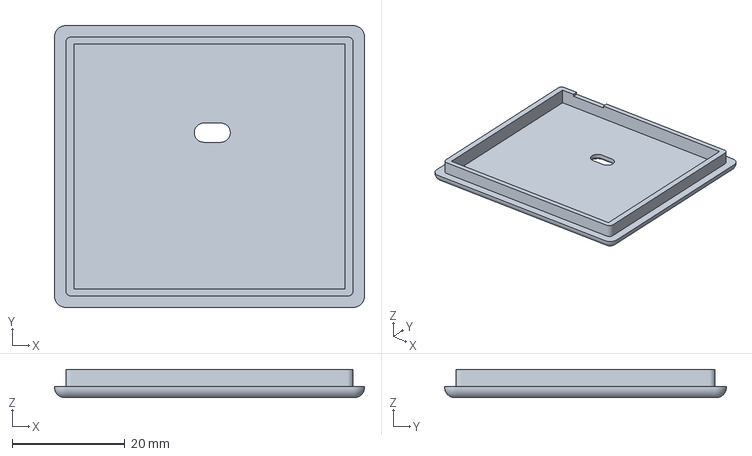
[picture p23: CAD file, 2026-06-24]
hardware/HCV-top-Körper.3mf
55.0 x 50.0 x 5.00 mm

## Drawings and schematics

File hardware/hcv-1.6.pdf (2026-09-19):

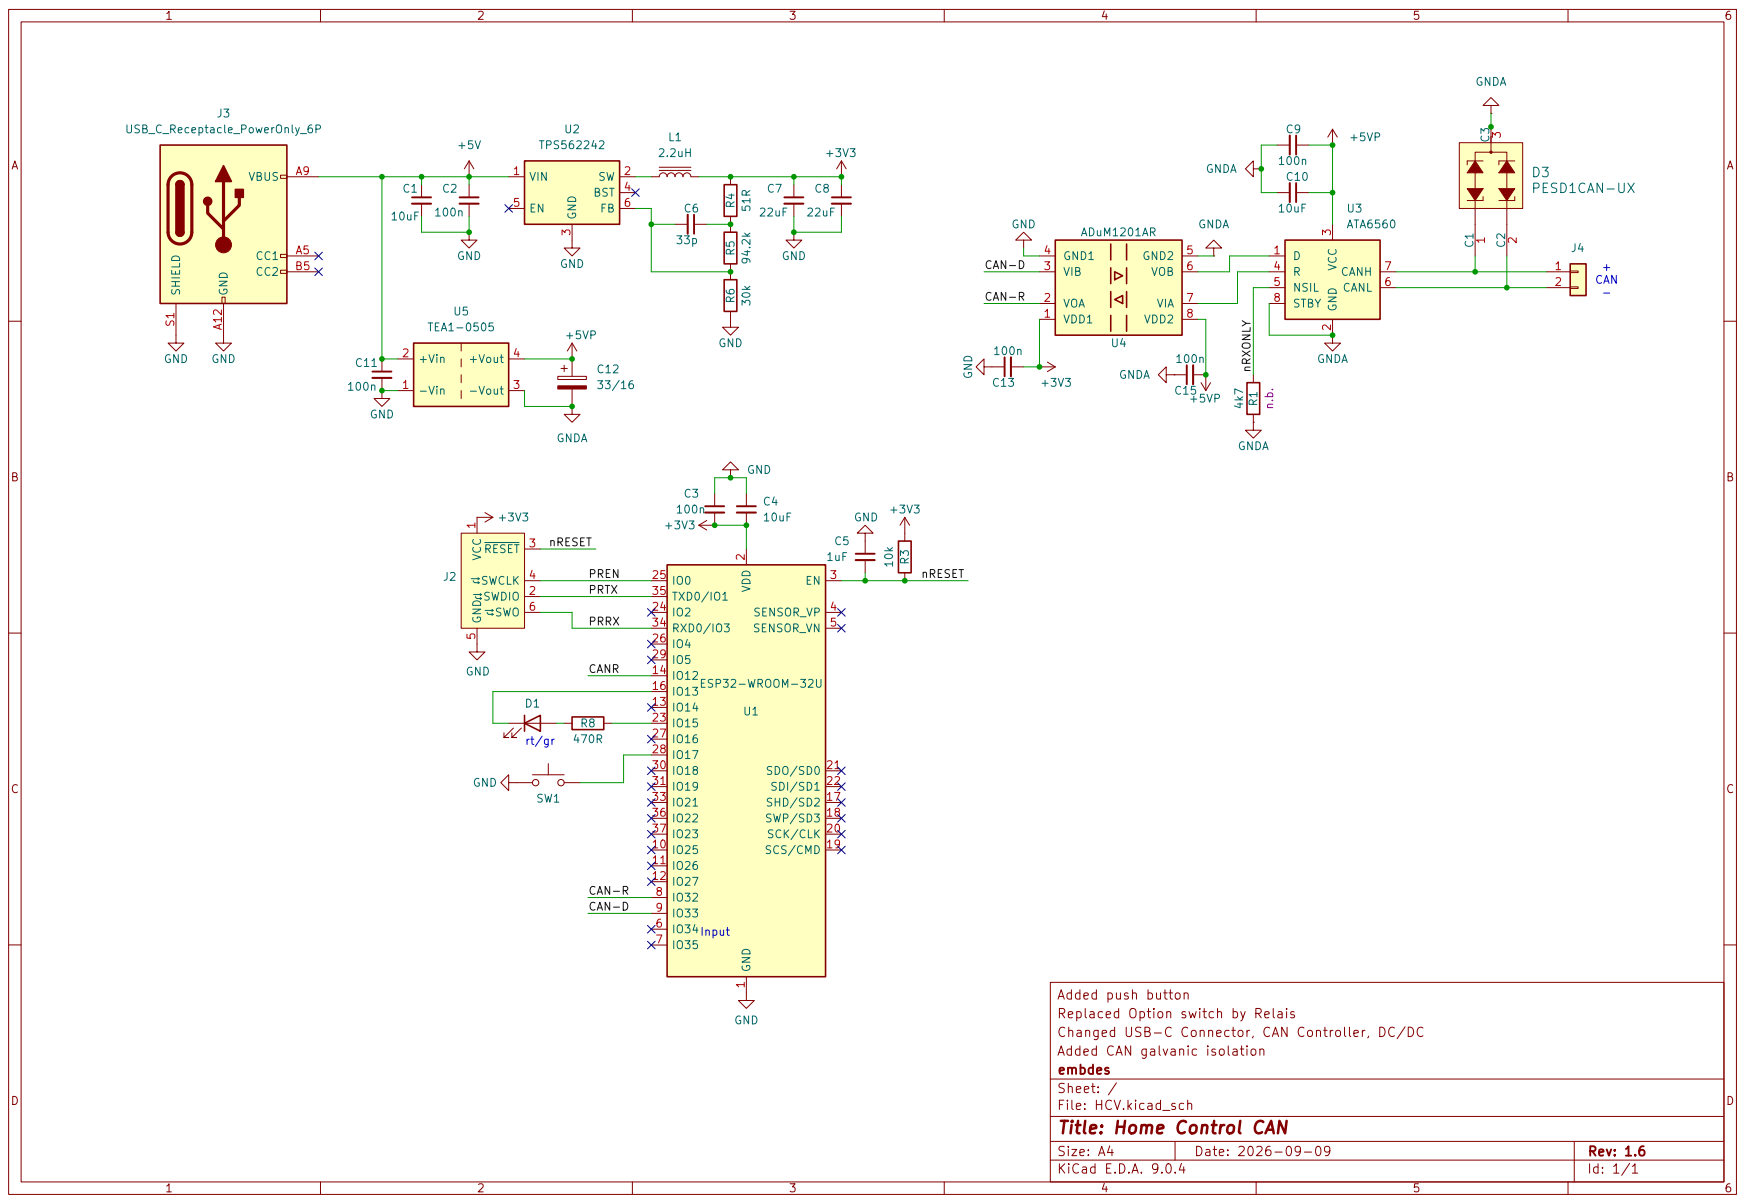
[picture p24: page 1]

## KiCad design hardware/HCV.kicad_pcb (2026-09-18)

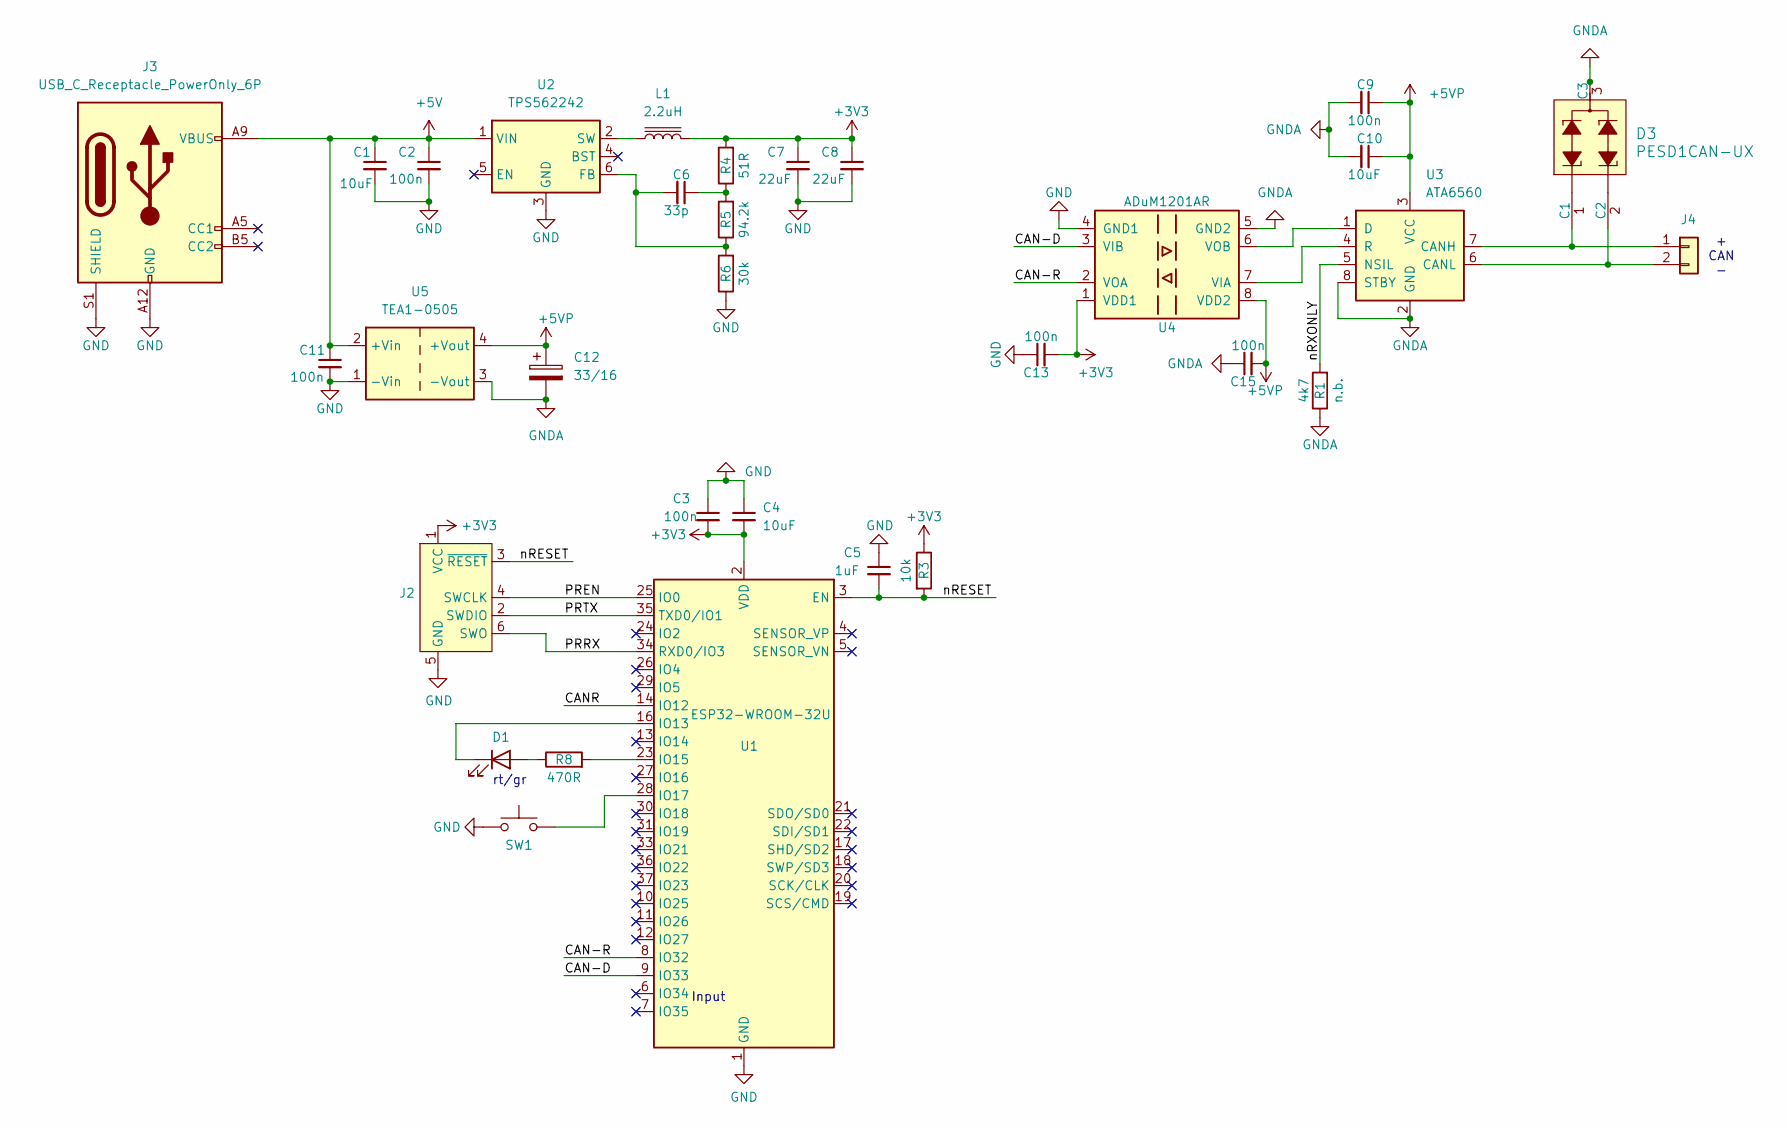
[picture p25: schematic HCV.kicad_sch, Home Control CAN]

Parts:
C1, C4, C10: 10uF; C_0805_2012Metric
C2, C3, C9, C11, C13, C15: 100n; C_0603_1608Metric
C5: 1uF; C_0603_1608Metric
C6: 33p; C_0603_1608Metric
C7, C8: 22uF; C_1206_3216Metric_Pad1.33x1.80mm_HandSolder
C12: 33/16; CP_EIA-3528-12_Kemet-T
D1: LED; LED_D3.0mm
D3: PESD1CAN-UX; SOT-23-3; MPN PESD1CAN-UX; Digi-Key_PN 1727-1306-1-ND
J2: Conn_ARM_SWD_TagConnect_TC2030; Tag-Connect_TC2030-IDC-FP_2x03_P1.27mm_Vertical
J3: USB_C_Receptacle_PowerOnly_6P; USB_C_Receptacle_GCT_USB4125-xx-x-0190_6P_TopMnt_Horizontal
J4: Conn_01x02; PhoenixContact_MC_1,5_2-G-3.5_1x02_P3.50mm_Horizontal
L1: 2.2uH; L_Bourns-SRN4018
R1: 4k7; R_0603_1608Metric
R3: 10k; R_0603_1608Metric
R4: 51R; R_0603_1608Metric
R5: 94.2k; R_0603_1608Metric
R6: 30k; R_0603_1608Metric
R8: 470R; R_0603_1608Metric
SW1: SW_Push; SW_SPST_EVPBF
U1: ESP32-WROOM-32U; ESP32-WROOM-32
U2: TPS562242; SOT-563
U3: ATA6560; SOIC-8_3.9x4.9mm_P1.27mm
U4: ADuM1201AR; SOIC-8_3.9x4.9mm_P1.27mm
U5: TEA1-0505; Converter_DCDC_TRACO_TEA1-xxxx_THT

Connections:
+3V3: C3.2, C4.2, C7.1, C8.1, C13.2, J2.1 (VCC), L1.2, R3.1, R4.2, U1.2 (VDD), U4.1 (VDD1)
+5V: C1.1, C2.1, C11.1, J3.A9 (VBUS), J3.B9 (VBUS), U2.1 (VIN), U5.2 (+Vin)
+5VP: C9.1, C10.1, C12.1, C15.2, U3.3 (VCC), U4.8 (VDD2), U5.4 (+Vout)
/CAN-D: U1.9 (IO33), U4.3 (VIB)
/CAN-R: U1.8 (IO32), U4.2 (VOA)
/CANR: U1.14 (IO12)
/PREN: J2.4 (SWCLK), U1.25 (IO0)
/PRRX: J2.6 (SWO), U1.34 (RXD0/IO3)
/PRTX: J2.2 (SWDIO), U1.35 (TXD0/IO1)
/nRESET: C5.2, J2.3 (~RESET), R3.2, U1.3 (EN)
/nRXONLY: R1.2, U3.5 (NSIL)
GND: C1.2, C2.2, C3.1, C4.1, C5.1, C7.2, C8.2, C11.2, C13.1, J2.5 (GND), J3.A12 (GND), J3.B12 (GND), J3.S1 (SHIELD), R6.1, SW1.1, U1.1 (GND), U1.15 (GND), U1.38 (GND), U1.39 (GND), U2.3 (GND), U4.4 (GND1), U5.1 (-Vin)
GNDA: C9.2, C10.2, C12.2, C15.1, D3.3 (C3), R1.1, U3.2 (GND), U3.8 (STBY), U4.5 (GND2), U5.3 (-Vout)
unnamed: C6.1, R4.1, R5.2
unnamed: D1.2 (A), R8.1
unnamed: D1.1 (K), U1.16 (IO13)
unnamed: D3.1 (C1), J4.1, U3.7 (CANH)
unnamed: D3.2 (C2), J4.2, U3.6 (CANL)
unnamed: R8.2, U1.23 (IO15)
unnamed: SW1.2, U1.28 (IO17)
unnamed: C6.2, R5.1, R6.2, U2.6 (FB)
unnamed: L1.1, U2.2 (SW)
unnamed: U3.1 (D), U4.6 (VOB)
unnamed: U3.4 (R), U4.7 (VIA)

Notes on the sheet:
rt/gr
+ CAN -
Input

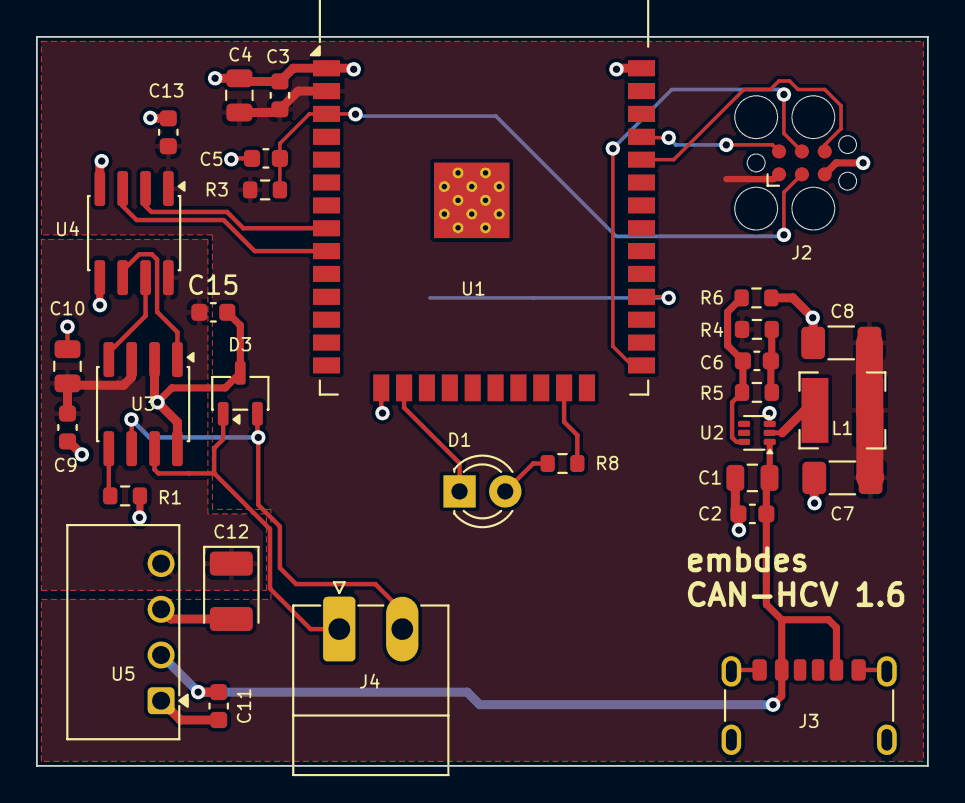
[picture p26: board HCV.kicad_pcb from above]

Board: 2 copper layers, 49.5 x 40.5 mm, 32 parts (1 on the bottom side), 23 nets.

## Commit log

2026-06-24 Added Hardware and Software
    [HCV-Körper.3mf, HCV-top-Körper.3mf, HCV.kicad_pcb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]
2026-06-27 Updated Docu, Updated Hardware
    [HCV.kicad_pcb, HCV.kicad_sch]
2026-08-11 Enhance README with CAN Bus Logging and DID Management
    Added sections for CAN Bus Logging and Data Identifier Management in the README.
2026-09-18 Update for HCV Hardware
    [HCV.kicad_pcb, HCV.kicad_sch]
2026-09-19 Added HCV 1.6 schematic.pdf
